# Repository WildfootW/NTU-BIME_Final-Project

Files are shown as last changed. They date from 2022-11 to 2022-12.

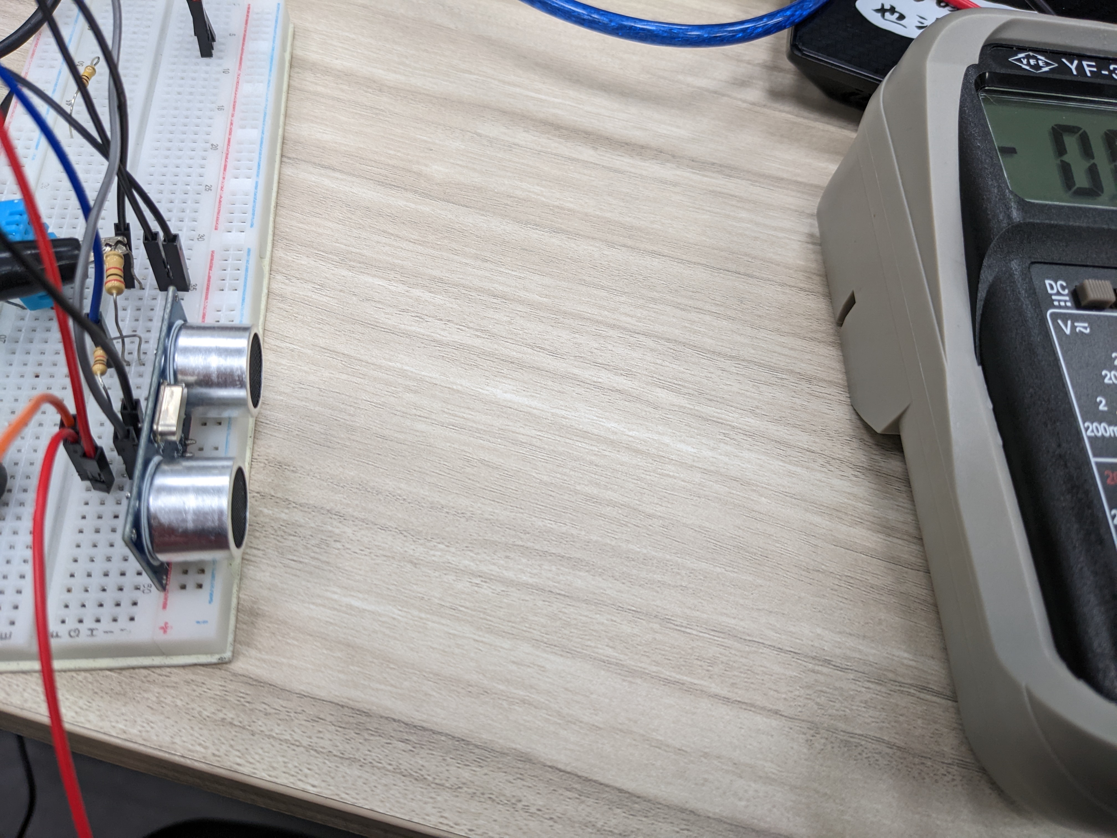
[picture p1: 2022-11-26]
Software/Components/HC-SR04/HC-SR04-2.3.jpg

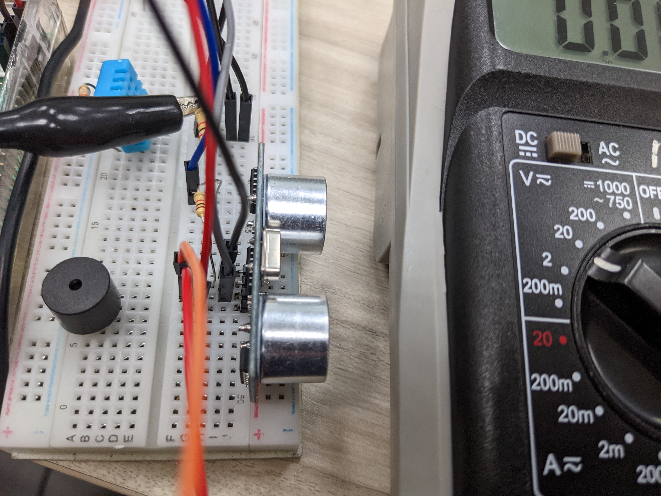
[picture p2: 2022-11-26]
Software/Components/HC-SR04/HC-SR04-1.3.jpg

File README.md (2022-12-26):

# BIME Final Project
###### tags: `README`
NTU BIME - Mechatronics 4 - Final Project

## Contributor
* Andrew 沈郁哲 (b07611012)
* Nick 張熯尹 (b08611038)
* Eric 張焜程 (b08611037)

### Work Distribution
* Program Manager: Andrew
* Platform Technical Manager: Andrew
* Mechanical - Main Structure: Eric
* Mechanical - Components: Eric
* Mechanical - Manufacturing: Eric
* Mechanical - Assembling: Eric, Nick
* Cable Management: Eric, Nick
* Industrial Design: Eric
* Thermal: Andrew
* Electrical - Schematic: Andrew
* Electrical - Layout: Andrew
* Electrical - Soldering: Andrew
* Software - Components: Nick
* Software - ROS: Nick, Andrew
* Software - OpenCV: Nick
* Supply Chain: Eric, Andrew
* Validation: Nick
* Driver: Nick
* Contact: Nick, Eric

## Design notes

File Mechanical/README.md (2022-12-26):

# BIME Final Project - Mechanical
[TOC]
###### tags: `Mechatronics`





## Main Deck
車子的主甲板，初版為直接將零件放在壓克力板上並手繪，再將其用電腦繪圖畫出，爾後買了紅色的大片壓克力板，用雷切機切出，其上乘載了大部分的零件，包括一片 RPi 、一片接在 RPi 上的電路板、兩個 H-bridge、兩個 HC-SR04 及一個伺服馬達。


## HC-SR04 Holder
3D 列印，作為 Sonar Sensor 的底座。


## Servo Motor Holder
3D 列印，將伺服馬達固定在主甲板上。


## Ring Ball Holder
作為我們設計的"夾爪"，一開始我的設計思路就是越簡單越好，最好是寫程式的人只需要做簡單的上下控制，於是想出了現在的這個環狀捕球器，畫圖時，先得知塑膠球的大小後，大概預測出捕球器所需的直徑，再將寬度和連接桿的長度依據車子設計的形狀做出決定，採用壓克力板雷切，尤其是我選用了比較厚的壓克力板，希望能更好的將球保持在環裡，最後用三秒膠固定在伺服馬達上。


## Motor Deck
放置四顆 TT 馬達的底板，並將很重的行動電源放置在馬達板的中間，使用壓克力板雷切製成。馬達板位於車體的最下層，以期將車子的重心盡量往下。


## TT Motor Holder
3D 列印，TT 馬達的固定座。

## Mecanum Wheel
當時我們決定使用四顆輪子，希望有更順暢的跑動，於是選用了麥克納姆輪，利用它能夠輕鬆執行前進、後退、旋轉、橫移的特點，升級我們電動車的跑動表現。
* Failed. Need two different direction x2. But we got same direction x4.

## Battery Deck
放置電池盒及 webcam holder 的板子，將電池板置於最上層，可以讓我們更好的更換電池，並且可以支撐我們的 webcam 收集影像所需的高度，讓我們的 webcam holder 不需很長很重，於壓克力板雷切製成。


## Webcam Holder
放置webcam的平台，提供webcam所需視野高度，3d列印製成。
* 
* SOLID, light-cured 3D printing
* 

## Car Garage
車子的美觀作品，作為電動車的車庫，讓車子由此衝出，由美術材料和冰棒棍製成。


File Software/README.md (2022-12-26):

# BIME Final Project - Software
[TOC]
###### tags: `Mechatronics`

# ROS

## Install
### Ubuntu
* [**ubuntu 20.04 ROS Noetic**](https://wiki.ros.org/ROS/Installation/TwoLineInstall/)
* [**Install ROS on Ubuntu**](https://wiki.ros.org/noetic/Installation/Ubuntu)
    * `wget -c https://raw.githubusercontent.com/qboticslabs/ros_install_noetic/master/ros_install_noetic.sh && chmod +x ./ros_install_noetic.sh && ./ros_install_noetic.sh`
### RPi & ROS from Source
* [**How to Install ROS Noetic on Raspberry Pi 4**](https://varhowto.com/install-ros-noetic-raspberry-pi-4/)
```
sudo sh -c 'echo "deb http://packages.ros.org/ros/ubuntu buster main" > /etc/apt/sources.list.d/ros-noetic.list'
sudo apt-key adv --keyserver 'hkp://keyserver.ubuntu.com:80' --recv-key C1CF6E31E6BADE8868B172B4F42ED6FBAB17C654
sudo apt update

sudo apt-get install -y python-rosdep python-rosinstall-generator python-wstool python-rosinstall build-essential cmake
sudo rosdep init
cat /etc/ros/rosdep/sources.list.d/20-default.list
rosdep update

mkdir ~/ros_catkin_ws
cd ~/ros_catkin_ws
rosinstall_generator ros_comm --rosdistro noetic --deps --wet-only --tar > noetic-ros_comm-wet.rosinstall
wstool init src noetic-ros_comm-wet.rosinstall
rosdep install -y --from-paths src --ignore-src --rosdistro noetic -r --os=debian:buster

sudo dphys-swapfile swapoff
sudo vim /etc/dphys-swapfile // CONF_SWAPSIZE=1024
sudo dphys-swapfile setup
sudo dphys-swapfile swapon
free -m

sudo src/catkin/bin/catkin_make_isolated --install -DCMAKE_BUILD_TYPE=Release --install-space /opt/ros/noetic -j1 -DPYTHON_EXECUTABLE=/usr/bin/python3
source /opt/ros/noetic/setup.bash
```
* [**Installing ROS Kinetic on the Raspberry Pi**](https://wiki.ros.org/ROSberryPi/Installing%20ROS%20Kinetic%20on%20the%20Raspberry%20Pi) - This is the official version for Kinetic. Has "Maintaining a Source Checkout"
```
cd ~/ros_catkin_ws
rosinstall_generator ros_comm ros_control joystick_drivers --rosdistro noetic --deps --wet-only --tar > noetic-custom_ros.rosinstall
rosinstall_generator ros_comm turtlesim usb_cam --rosdistro noetic --deps --wet-only --tar > noetic-custom_ros.rosinstall

wstool merge -t src noetic-custom_ros.rosinstall
wstool update -t src

rosdep install -y --from-paths src --ignore-src --rosdistro noetic -r --os=debian:buster
sudo src/catkin/bin/catkin_make_isolated --install -DCMAKE_BUILD_TYPE=Release --install-space /opt/ros/noetic -j1 -DPYTHON_EXECUTABLE=/usr/bin/python3
```
### Packages
* `sudo apt-get install ros-$(rosversion -d)-`
* `sudo apt-get install ros-$(rosversion -d)-turtlesim`

### Issues
#### INSTALL ROSDEP
* 建立 package 遇到問題
* 

#### Build only the pkg

https://answers.ros.org/question/54178/how-to-build-just-one-package-using-catkin_make/
`sudo src/catkin/bin/catkin_make_isolated --only-pkg-with-deps bime_final --merge -j2 -DPYTHON_EXECUTABLE=/usr/bin/python3`

#### Can't Execute ROSRUN after source devel/setup.bash
[Ros commands no longer working after source catkin_ws/devel/setup.bash](https://answers.ros.org/question/349276/ros-commands-no-longer-working-after-source-catkin_wsdevelsetupbash/)
* `source /opt/ros/melodic/setup.bash` and then `source devel/setup.bash --extend`

* `sudo src/catkin/bin/catkin_make_isolated --install -DCMAKE_BUILD_TYPE=Release --install-space /opt/ros/noetic -j2 -DPYTHON_EXECUTABLE=/usr/bin/python3`
    * would repair, but very slow on RPi (Seems recompile whole ROS system)

#### catkin_make vs catkin_make_isolated
* [catkin_make vs catkin_make_isolated, which is preferred?](https://answers.ros.org/question/320613/catkin_make-vs-catkin_make_isolated-which-is-preferred/)


## Connect Master
* [**Connecting Raspberry Pi with PC over LAN**](https://razbotics.wordpress.com/2018/01/23/ros-distributed-systems/)

## Components
### DHT11
[DHT11 introudction](https://blog.csdn.net/wgj99991111/article/details/53749144)


### OpenCV / Camera
* [Ball Track](https://github.com/tizianofiorenzani/ros_tutorials/tree/master/opencv)
* [CV Camera Tourial](https://www.theconstructsim.com/how-to-install-a-usb-camera-in-turtlebot3/)
* [opencv turtlebot2-tutorials](https://dabit-industries.github.io/turtlebot2-tutorials/14b-OpenCV2_Python.html)
[ROS Developers LIVE Class #86: How to use OpenCV with ROS](https://www.youtube.com/watch?v=0C0gOsLoP9k)
* [cv camera](https://www.theconstructsim.com/how-to-install-a-usb-camera-in-turtlebot3/)
* [cv tracking object](https://github.com/behnamasadi/OpenCVProjects)
* [ROS Tutorial 001: Remotely connecting to webcam using Raspberry Pi 3 and ROS](https://github.com/yev-d/tutos/blob/master/ROS/Tutorial-001/Remotely-connecting-to-webcam-using-Raspberry-Pi-3-and-ROS.md)
* [How to use USB camera with ROS on Raspberry Pi - image_view and web streaming](https://roboticsweekends.blogspot.com/2017/12/how-to-use-usb-camera-with-ros-on.html)
* [rosmaster connect](https://hollyqood.wordpress.com/2017/05/17/ros%E4%B8%8A%E5%90%8C%E6%99%82%E4%BD%BF%E7%94%A8%E5%A4%9A%E5%80%8B%E7%92%B0%E5%A2%83%E9%80%A3%E6%8E%A5masterroscore/) error: cannot connect 
* [**How to use a USB camera with ROS on the Raspberry Pi or BeagleBone Blue - for streaming video to a large computer**](https://sudonull.com/post/14791-How-to-use-a-USB-camera-with-ROS-on-the-Raspberry-Pi-or-BeagleBone-Blue-for-streaming-video-to-a-lar)
* [usb_cam Package Summary](http://wiki.ros.org/usb_cam#usb_cam_node)
* [camera_calibration set_camera_info Service not found](https://answers.ros.org/question/200154/camera_calibration-set_camera_info-service-not-found/)
#### Issues
* [image_view-2] process has died [pid 2280, exit code -11, cmd /opt/ros/noetic/lib/image_view/image_view image:=/usb_cam/image_raw __name:=image_view __log:=/home/ubuntu/.ros/log/ac8e131c-5993-11ed-ba8b-c538adf0cb0e/image_view-2.log].
log file: /home/ubuntu/.ros/log/ac8e131c-5993-11ed-ba8b-c538adf0cb0e/image_view-2*.log
    * [usb cam error](https://www.twblogs.net/a/5c0a98e1bd9eee6fb37bccd7)
* [usb cam service](https://answers.ros.org/question/200154/camera_calibration-set_camera_info-service-not-found/)

##### USB_CAM Launch

* Can be ignore on RPi. only need image-view on VM

##### Webcam Issue
* [**Ubuntu Community Webcam**](https://help.ubuntu.com/community/Webcam)
```
sudo usermod -a -G video $LOGNAME 
sudo apt install v4l-utils
sudo apt install ffmpeg
ffplay -f video4linux2 -input_format mjpeg -framerate 5 -video_size 640*480 /dev/video0
```


```
Driver Info:                    
        Driver name      : uvcvideo                                     
        Card type        : UVC Camera (046d:081b)
        Bus info         : usb-0000:02:03.0-1           
        Driver version   : 5.15.64
        Capabilities     : 0x84a00001
                Video Capture                                           
                Metadata Capture                                        
                Streaming
                Extended Pix Format                                                                                                              
                Device Capabilities                                                                                                              
        Device Caps      : 0x04200001
                Video Capture                                           
                Streaming                                               
                Extended Pix Format
Media Driver Info:                                                                                                                               
        Driver name      : uvcvideo                                                                                                              
        Model            : UVC Camera (046d:081b)                                                                                                
        Serial           : 9D37D020                                     
        Bus info         : usb-0000:02:03.0-1                                                                                                    
        Media version    : 5.15.64                                                                                                               
        Hardware revision: 0x00000012 (18) 
        Driver version   : 5.15.64                                      
Interface Info:                                                         
        ID               : 0x03000002                                                                                                            
        Type             : V4L Video                                                                                                             
Entity Info:                                                                                                                                     
        ID               : 0x00000001 (1)                                                                                                        
        Name             : UVC Camera (046d:081b)
        Function         : V4L2 I/O                                     
        Flags         : default                                                                                                                  
        Pad 0x01000007   : 0: Sink                                      
          Link 0x02000019: from remote pad 0x100000a of entity 'Extension 4': Data, Enabled, Immutable
Priority: 2
Video input : 0 (Camera 1: ok)
Format Video Capture:
        Width/Height      : 640/480
        Pixel Format      : 'MJPG' (Motion-JPEG)
        Field             : None
        Bytes per Line    : 0
        Size Image        : 614400
        Colorspace        : sRGB
        Transfer Function : Rec. 709
        YCbCr/HSV Encoding: ITU-R 601
        Quantization      : Default (maps to Full Range)
        Flags             : 
Crop Capability Video Capture:
        Bounds      : Left 0, Top 0, Width 640, Height 480
        Default     : Left 0, Top 0, Width 640, Height 480
        Pixel Aspect: 1/1
Selection Video Capture: crop_default, Left 0, Top 0, Width 640, Height 480, Flags: 
Selection Video Capture: crop_bounds, Left 0, Top 0, Width 640, Height 480, Flags: 
Streaming Parameters Video Capture:
        Capabilities     : timeperframe
        Frames per second: 5.000 (5/1)
        Read buffers     : 0
                     brightness 0x00980900 (int)    : min=0 max=255 step=1 default=128 value=128
                       contrast 0x00980901 (int)    : min=0 max=255 step=1 default=32 value=32
                     saturation 0x00980902 (int)    : min=0 max=255 step=1 default=32 value=32
 white_balance_temperature_auto 0x0098090c (bool)   : default=1 value=1
                           gain 0x00980913 (int)    : min=0 max=255 step=1 default=64 value=1
           power_line_frequency 0x00980918 (menu)   : min=0 max=2 default=2 value=2
                                0: Disabled
                                1: 50 Hz
                                2: 60 Hz
      white_balance_temperature 0x0098091a (int)    : min=0 max=10000 step=10 default=4000 value=1070 flags=inactive
                      sharpness 0x0098091b (int)    : min=0 max=255 step=1 default=24 value=24
         backlight_compensation 0x0098091c (int)    : min=0 max=1 step=1 default=0 value=0
                  exposure_auto 0x009a0901 (menu)   : min=0 max=3 default=3 value=3
                                1: Manual Mode
                                3: Aperture Priority Mode
              exposure_absolute 0x009a0902 (int)    : min=1 max=10000 step=1 default=166 value=656 flags=inactive
         exposure_auto_priority 0x009a0903 (bool)   : default=0 value=1
```
* fixed: need to set the USB port to 3.1



# UbiquityRobotics (Discard)
* https://learn.ubiquityrobotics.com/noetic_pi_image_downloads
* Strange behavior - discard
## rpi wifi connect
[wifi connect](https://learn.ubiquityrobotics.com/noetic_quick_start_microsd)
[wifi connect](https://learn.ubiquityrobotics.com/noetic_quick_start_connecting)
```
pifi list seen
sudo pifi add EELAB-Teach-5G bime0307
sudo pifi add Xiaomi5G 83662290
sudo pifi add Xiaomi5G ntubime405
sudo pifi add BBLAB_New ntubime405 
sudo reboot
```

## Issues
*

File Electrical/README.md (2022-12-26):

# BIME Final Project - Electrical
[TOC]
###### tags: `Mechatronics`

# BIME Final ~~HAT~~ PCB
* Reference Diameter
    * 

 
 

* [How to Export Gerber](https://www.elecrow.com/wiki/index.php?title=How_to_export_gerber_files_from_Altium_designer)

## Todo
* add Pinout
* Add 6V Switch
* Correct Fan Position
* repoly first layer
* reverse 10x2 pin
* Correct Resistor Ohm (R6789)

https://roboticsbackend.com/raspberry-pi-3-pins/#Reserved_pins
[**raspberrypi / hats**](https://github.com/raspberrypi/hats)
* move buzzer to pin7
* move Fan_Tach to pin26

## 3V3 to 5V
### Unidirectional
* [Amplify PWM Signal from exactly 0-3.3V to 0-5V](https://electronics.stackexchange.com/questions/359994/amplify-pwm-signal-from-exactly-0-3-3v-to-0-5v)
* Gate
    * 
* BJT
    * 
* [Auto fan control trouble shooting](https://forums.raspberrypi.com/viewtopic.php?t=328330)
    * 


### Bidirectional OC/OD open-collector or open-drain
* Buffer
    * [ I2C buffers overview ](https://youtu.be/WZWSB2-kvuA)
    * 
* Translator
    * [ I2C translators overview ](https://youtu.be/_Rxt1LLvtf4)
    * 
    
* Compiled Tips ‘N Tricks Guide


# Buck Converter
* [EasyEDA Project](https://u.easyeda.com/account/user/projects/index/detail?project=bbbc860793c24aa5b11dd05bab18da10&folder=all)

## Manufacture
* JLCPCBA
* [【教學】最簡單的PCB電路板教學，從設計到廠商製造一次搞定。JLCPCB](https://youtu.be/yPJ-4nEXykE)
* [製作自己的第一片PCB—使用JLCPCB、EasyEDA](https://bo-sgoldhouse.blogspot.com/2021/08/pcb-jlcpcb-easyeda.html)
* 
* 

## RPi 3B+ Power
* [Cable](https://shopee.tw/-%E7%89%A9%E8%81%AF%E6%B1%AA%E6%B1%AA-%E5%AF%A6%E7%94%A8-Micro-USB-%E9%96%8B%E9%97%9C%E5%85%85%E9%9B%BB%E7%B7%9A%E9%9B%BB%E6%BA%90%E7%B7%9A%E9%81%A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)
* [What is the expected behaviour of the PWR LED on Pi3B+](https://forums.raspberrypi.com/viewtopic.php?t=212350)
* [RPi 3 B: Strange behaviour of power LED](https://forums.raspberrypi.com/viewtopic.php?t=147447)
* [What do system LEDs signify?](https://raspberrypi.stackexchange.com/questions/871/what-do-system-leds-signify/60563#60563)
* [Raspberry Pi 3 Model B+ Stable Red Light When Powered Up](https://raspberrypi.stackexchange.com/questions/83090/raspberry-pi-3-model-b-stable-red-light-when-powered-up)
* 
* 

## Circuit



### MP2315
[How to Design 12V to 5V Buck Converter 一起设计一款好用的12V转5V电源模块](https://www.youtube.com/playlist?list=PLBpCr1fi_kFbyh0TMSjQk9jeb3ThH9svX)

#### Schematic




#### Layout
* Ver.傳奇帝 
	* https://oshwhub.com/jie.li/dcdc_mp2315
	* 
	* 
	* 

* Ver.孫
	* https://oshwhub.com/sunhaoqin/dcdc_mp2315
	* 
	* 
    
#### Test
* No Loading
    * 
* RPi Power on
    * 
* RPi not stable while operation
    * 
    * The PWR LED will turn off if the current of 12V over 0.3A. The RPi did not reset. The oscilloscope can neither find the 5V drop.
    * Replace the module by LM-2596. The PWR LED become more stable with less LED off. The current is less.
    * Connect the USB A direct to 5V Power supply. The PWR LED is stable as LM-2596. (not for sure). And current below 0.2A.
    * Connect with my power bank. RPi is not stable as well.
    * Connect direct to AC Converter. The PWR LED is very stable.

### LM-2596

* [ LM2596S 降壓電源 DC-DC 降壓型 電源模組  具備電源指示燈 ](https://www.taiwaniot.com.tw/product/lm2596s-%E9%99%8D%E5%A3%93%E9%9B%BB%E6%BA%90-dc-dc-%E9%99%8D%E5%A3%93%E5%9E%8B-%E9%9B%BB%E6%BA%90%E6%A8%A1%E7%B5%84-%E5%8F%AF%E8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)

#### Module
* Fake LM2596 & Detail Test
* [ Counterfeit LM2596 Regulator Boards ](https://k6jca.blogspot.com/2018/02/counterfeit-lm2596-regulator-boards.html)
*

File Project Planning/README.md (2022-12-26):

# BIME Final Project - Components
[TOC]
###### tags: `Mechatronics`

# Software & Circuit
## Reference
* [Duckiebot](https://docs.duckietown.org/daffy/opmanual_duckiebot/out/duckiebot_configurations.html)
* [ nasa-jpl / open-source-rover ](https://github.com/nasa-jpl/open-source-rover)
* ROS Ecosystem
* [t1m0thyj / picar](https://github.com/t1m0thyj/picar)
    * [ How to Make Raspberry Pi Car at home ](https://youtu.be/FyMq5KOcgTg)

## Communication
### Video Transmitter
[ 5.8GHz Vs. 1300MHz FPV Penetrating Power Test - RCTESTFLIGHT - ](https://youtu.be/LltDtKs2sQ4)

### FPV Transmitter / Receiver
* [Drones and Model Aircraft - Frequency](https://drones.stackexchange.com/questions/810/why-is-5-8ghz-used-for-fpv-and-2-4ghz-use-for-transmitters)


### On Screen Display (OSD)
* [Raspberry Pi Zero FPV camera and OSD](https://hackaday.io/project/12450-raspberry-pi-zero-fpv-camera-and-osd)

### Direction

## Power
* Battery
* BMS

RPi input from USB Header 5V

http://www.pidramble.com/wiki/benchmarks/power-consumption

## Sensor
### Camera
* C310 HD
* Intel® RealSense™ depth camera D435

### Obstacle
* Depth Camera
* Sonic
* IR

### Thermal
https://lastminuteengineers.com/mlx90614-ir-temperature-sensor-arduino-tutorial/

測量熱源的關卡設定是在熱源前面35-45公分處（助教指定距離），定位後車輛停止五秒感測溫度，目前實際測試看來，溫度在攝氏40-45度之間。



* Fan

### Accelerometer?
MPU-6050


https://shop.cpu.com.tw/product/45284/info/

## Actuator
### PWM
* [Adafruit 16-Channel 12-bit PWM/Servo Driver - I2C interface - PCA9685](https://www.adafruit.com/product/815)
* [What's the difference between soft PWM and PWM](https://raspberrypi.stackexchange.com/questions/100641/whats-the-difference-between-soft-pwm-and-pwm)
* [ besp9510 /dma_pwm ](https://github.com/besp9510/dma_pwm)
### H-Bridge


### Wheel Motor
* [Adafruit TT](https://www.adafruit.com/product/3777)
* 
* 

### Gripper
* [Tower Pro SG90](https://www.towerpro.com.tw/product/sg90-7/)
* 

### Buzzer

# Mechanical
## References
* [A gamified simulator and physical platform for self-driving algorithm training and validation](https://www.researchgate.net/figure/This-1-10th-scale-buggy-features-a-Raspberry-Pi-3B-Navio2-interface-board-Logitech_fig10_337336443)
    * 
* [ nasa-jpl /open-source-rover ](https://github.com/nasa-jpl/open-source-rover)

## Car Body
* 4x Mecanum wheel W/O Suspenstion
* 4x Mecanum wheel W/ Suspenstion
    * https://youtu.be/K1yDDmkbaq4
* 3x Omni Wheel
* 4x Normal Wheel W/ Suspension
    * HSP94186 (https://youtu.be/iLiI_IRedhI)
    * [Donkey® Car](https://docs.donkeycar.com)
* 4x Normal Wheel W/O Suspension
* 2x Normal Wheel W/ Ball Roller
    * [Li-Wei Yang - Mechatronics 4](https://youtu.be/lFlVofkHzSU)

## Gripper
* 球的直徑大約為6.6-6.7公分

## Holders
* Camera
* Thermal
* ...

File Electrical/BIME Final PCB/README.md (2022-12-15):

* [Buck Converter MP2315](https://oshwlab.com/wildfootw/buck-converter-mp2315)

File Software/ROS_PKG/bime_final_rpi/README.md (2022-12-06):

# ROS PKG - bime_final_rpi
## Cheatsheet
* Compile this package on RPi
```
sudo src/catkin/bin/catkin_make_isolated --only-pkg-with-deps bime_final_rpi --merge -j4 -DPYTHON_EXECUTABLE=/usr/bin/python3
```

## Basic Information
### Dependence
* [USB_CAM](https://index.ros.org/p/usb_cam/github-ros-drivers-usb_cam/)

## Component
### Mecanum wheel
Move Direction

## Reference
[Raspberry Pi - PWM](https://sourceforge.net/p/raspberry-gpio-python/wiki/PWM/)

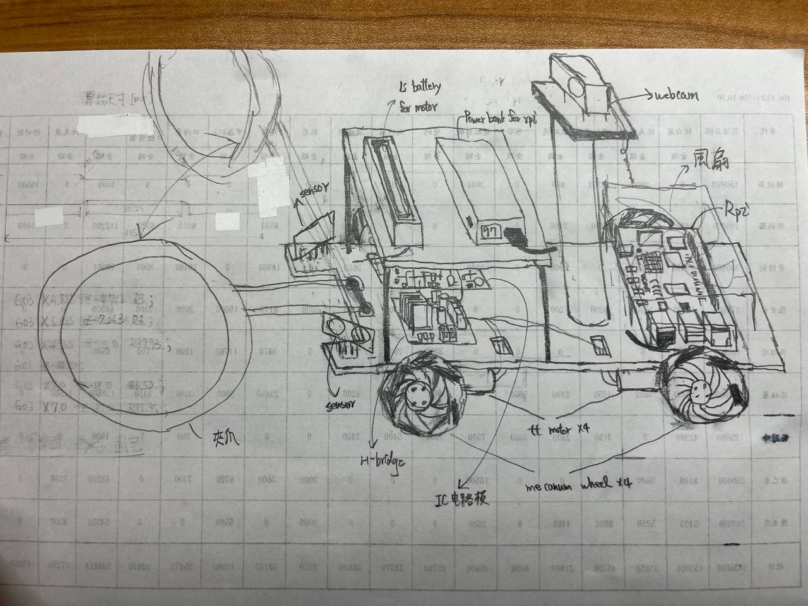
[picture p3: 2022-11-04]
Mechanical/Mechanical Prototype v1.0.jpg

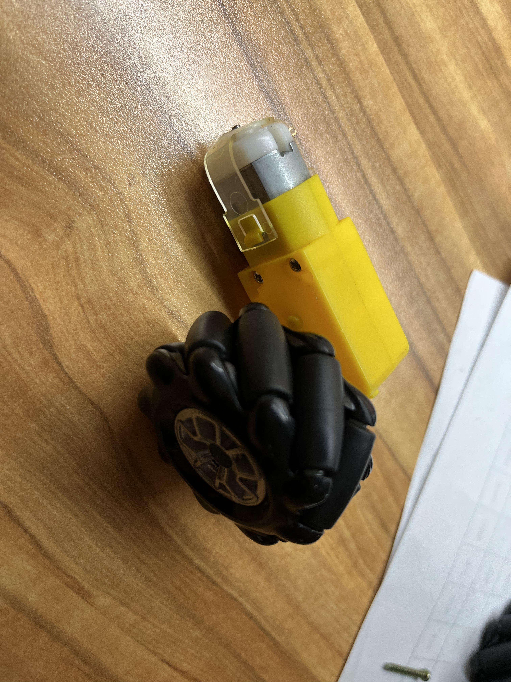
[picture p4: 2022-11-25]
Mechanical/Mecanum Wheel.jpg

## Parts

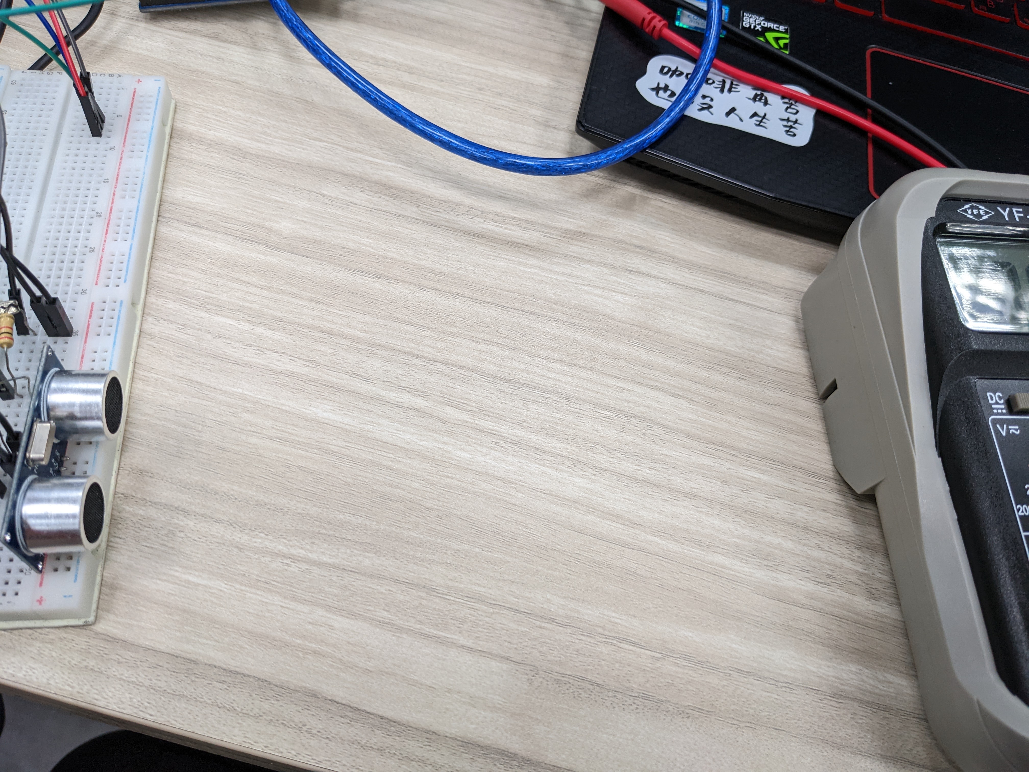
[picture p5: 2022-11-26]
Software/Components/HC-SR04/HC-SR04-3.3.jpg

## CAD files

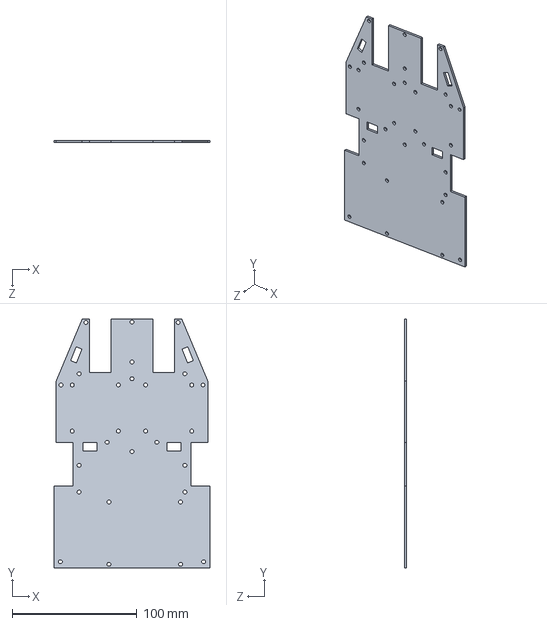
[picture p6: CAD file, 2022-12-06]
Mechanical/Main Deck.SLDPRT
125.0 x 200.0 x 2.00 mm

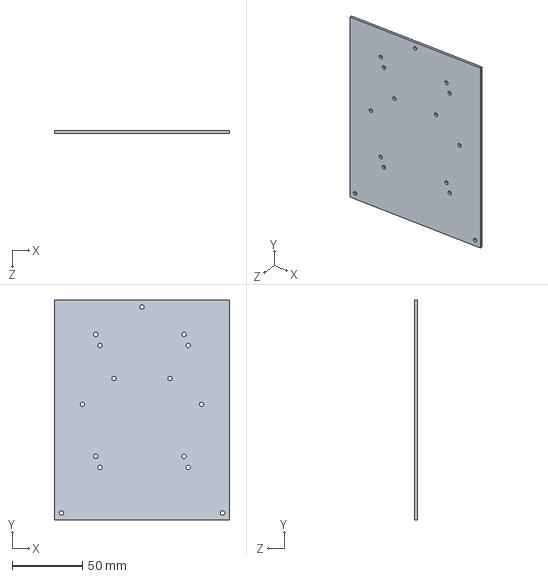
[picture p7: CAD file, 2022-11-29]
Mechanical/Motor Deck.SLDPRT
125.0 x 157.0 x 2.00 mm

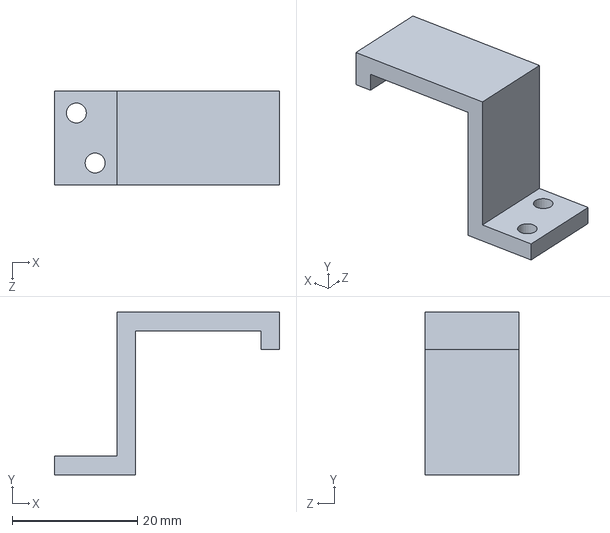
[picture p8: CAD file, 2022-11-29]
Mechanical/TT Motor Holder.SLDPRT
36.0 x 26.0 x 15.0 mm

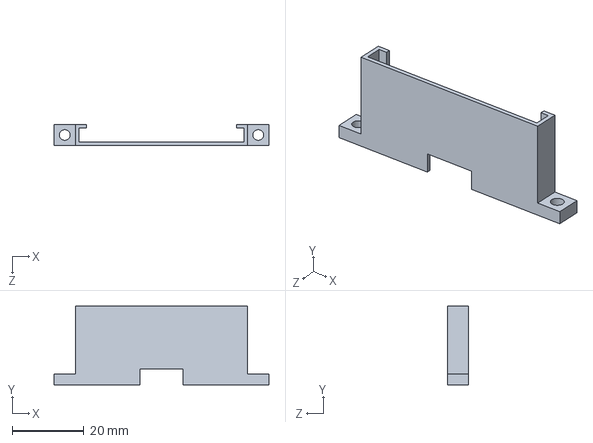
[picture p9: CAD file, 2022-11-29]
Mechanical/HC-SR04 Holder.SLDPRT
60.0 x 22.0 x 6.00 mm

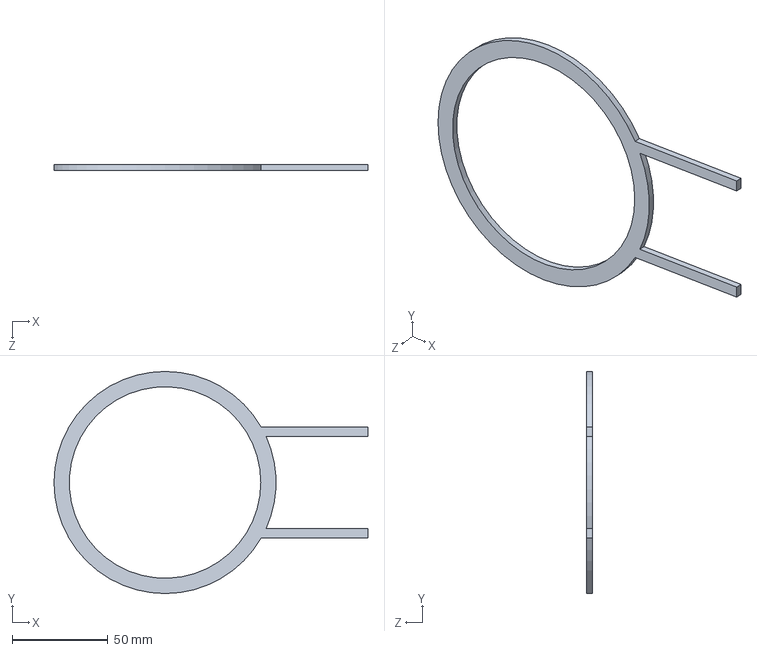
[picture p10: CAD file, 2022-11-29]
Mechanical/Ring Ball Holder.SLDPRT
164.0 x 116.0 x 3.00 mm

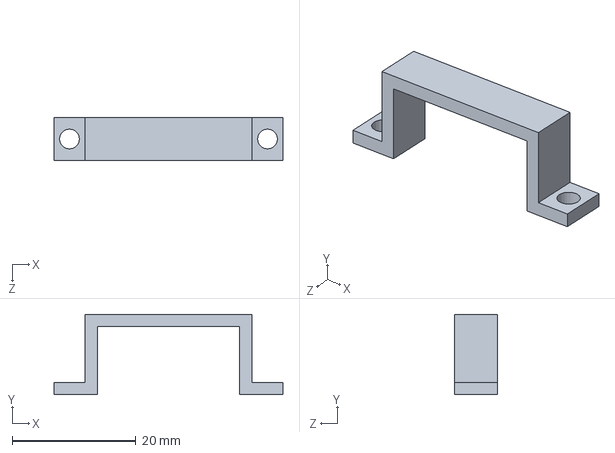
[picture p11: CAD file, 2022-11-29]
Mechanical/Servo Motor Holder.SLDPRT
37.0 x 13.0 x 7.00 mm

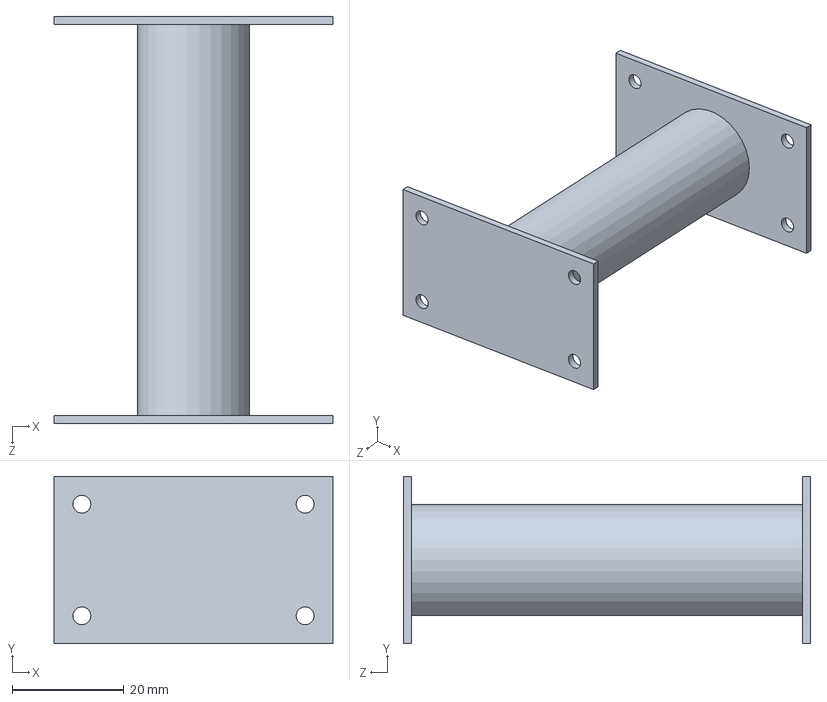
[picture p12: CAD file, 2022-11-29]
Mechanical/Webcam Holder.SLDPRT
50.0 x 30.0 x 73.0 mm

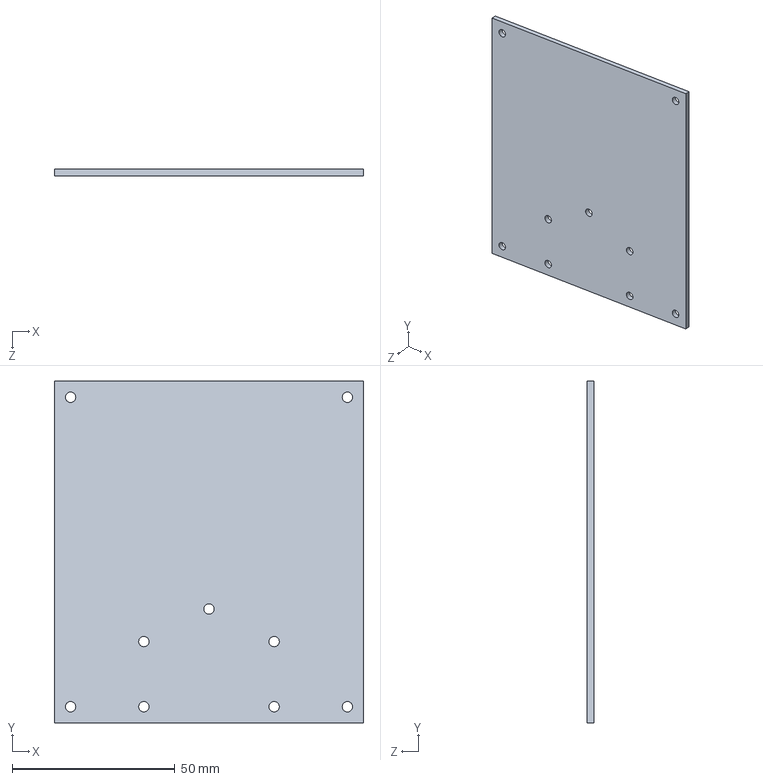
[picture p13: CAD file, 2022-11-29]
Mechanical/Battery Deck.SLDPRT
95.0 x 105.0 x 2.00 mm

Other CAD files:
Electrical/BIME Final PCB/BoardShape.SLDPRT
Electrical/BIME Final PCB/BoardShape.DXF
Mechanical/Battery Deck.DXF
Mechanical/HC-SR04 Holder.STL
Mechanical/Main Deck.DXF
Mechanical/Motor Deck.DXF
Mechanical/Ring Ball Holder.DXF
Mechanical/Servo Motor Holder.STL
Mechanical/TT Motor Holder.STL
Mechanical/Webcam Holder.STL

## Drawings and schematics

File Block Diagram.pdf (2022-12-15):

VM

### Ubuntu 20.04

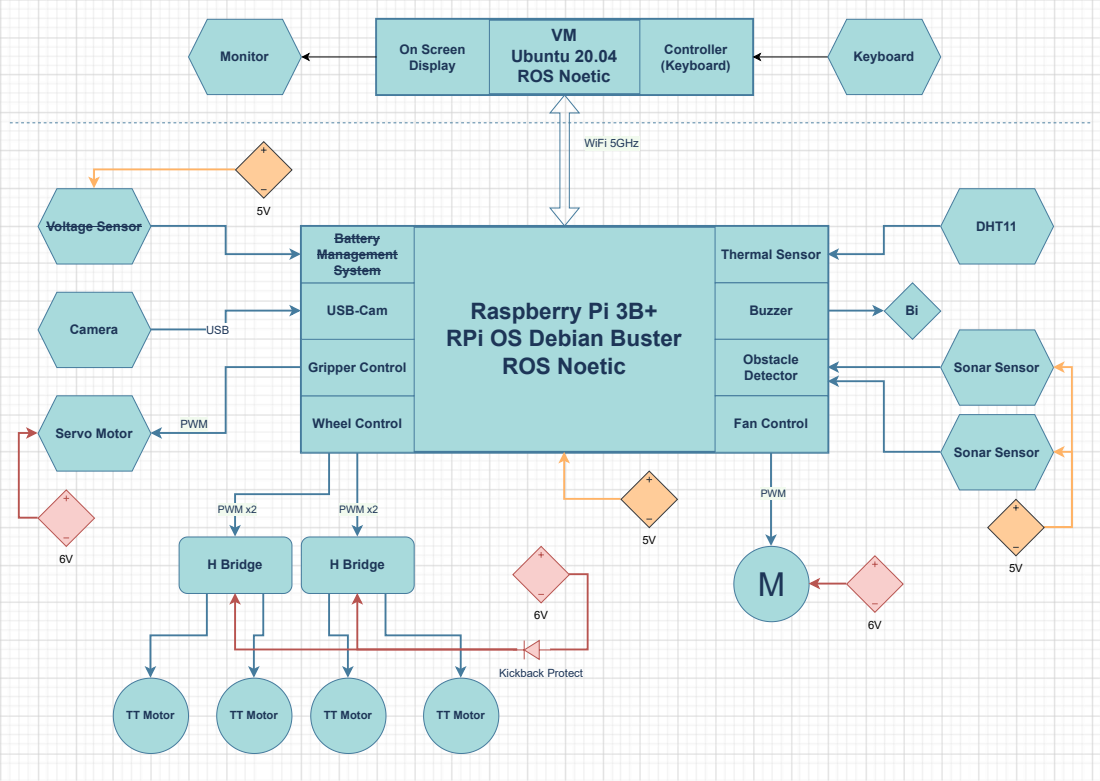
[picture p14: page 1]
ROS Noetic; WiFi 5GHz; PWM x2; PWM; Wheel Control; Gripper Control; USB-Cam; Battery Management System; Thermal Sensor; Buzzer; Obstacle Detector; Fan Control; Voltage Sensor; Camera; USB; Servo Motor; H Bridge; DHT11; Sonar Sensor; TT Motor; Kickback Protect; On Screen Display; Controller (Keyboard); Monitor; Keyboard

Raspberry Pi 3B+
RPi OS Debian Buster
ROS Noetic

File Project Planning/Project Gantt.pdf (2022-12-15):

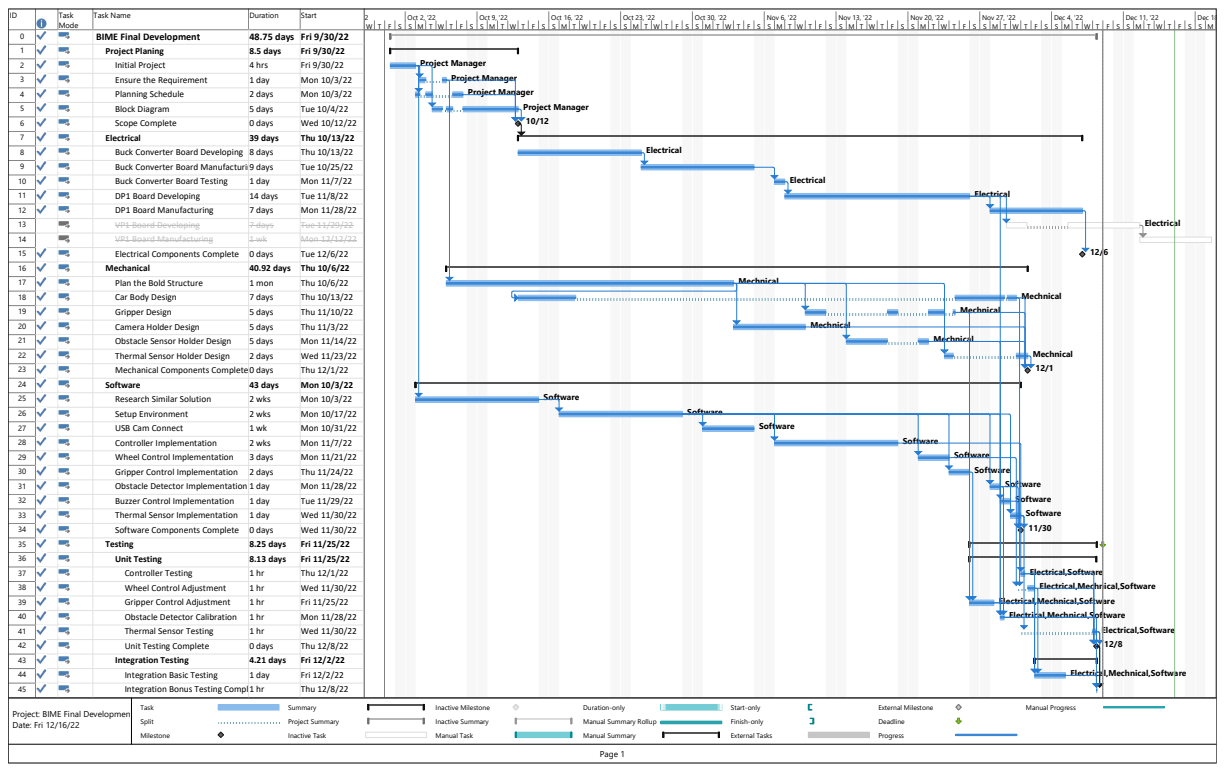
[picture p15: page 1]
Project Manager; Project Manager 10/12; Electrical; Mechnical; Mechnical 12/1; Software Software Software 11/30; Electrical,Software 12/8; Oct 2, '22; Oct 9, '22; Oct 16, '22; Oct 23, '22; Oct 30, '22; Nov 6, '22; Nov 13, '22; Nov 20, '22; Nov 27, '22; Dec 4, '22; Dec 11, '22; Dec 18, '22; Task; Split; Milestone; Summary; Project Summary; Inactive Task; Inactive Milestone; Inactive Summary; Manual Task; Start-only; Finish-only; External Tasks; External Milestone; Deadline; Progress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

ID | Task Mode | Task Name | Duration | Start
0 | | BIME Final Development | 48.75 days | Fri 9/30/22
1 | | Project Planing | 8.5 days | Fri 9/30/22
2 | | Initial Project | 4 hrs | Fri 9/30/22
3 | | Ensure the Requirement | 1 day | Mon 10/3/22
4 | | Planning Schedule | 2 days | Mon 10/3/22
5 | | Block Diagram | 5 days | Tue 10/4/22
6 | | Scope Complete | 0 days | Wed 10/12/22
7 | | Electrical | 39 days | Thu 10/13/22
8 | | Buck Converter Board Developing | 8 days | Thu 10/13/22
9 | | Buck Converter Board Manufacturing9 days | | Tue 10/25/22
10 | | Buck Converter Board Testing | 1 day | Mon 11/7/22
11 | | DP1 Board Developing | 14 days | Tue 11/8/22
12 | | DP1 Board Manufacturing | 7 days | Mon 11/28/22
13 | | VP1 Board Developing | 7 days | Tue 11/29/22
14 | | VP1 Board Manufacturing | 1 wk | Mon 12/12/22
15 | | Electrical Components Complete | 0 days | Tue 12/6/22
16 | | Mechanical | 40.92 days | Thu 10/6/22
17 | | Plan the Bold Structure | 1 mon | Thu 10/6/22
18 | | Car Body Design | 7 days | Thu 10/13/22
19 | | Gripper Design | 5 days | Thu 11/10/22
20 | | Camera Holder Design | 5 days | Thu 11/3/22
21 | | Obstacle Sensor Holder Design | 5 days | Mon 11/14/22
22 | | Thermal Sensor Holder Design | 2 days | Wed 11/23/22
23 | | Mechanical Components Complete0 days | | Thu 12/1/22
24 | | Software | 43 days | Mon 10/3/22
25 | | Research Similar Solution | 2 wks | Mon 10/3/22
26 | | Setup Environment | 2 wks | Mon 10/17/22
27 | | USB Cam Connect | 1 wk | Mon 10/31/22
28 | | Controller Implementation | 2 wks | Mon 11/7/22
29 | | Wheel Control Implementation | 3 days | Mon 11/21/22
30 | | Gripper Control Implementation | 2 days | Thu 11/24/22
31 | | Obstacle Detector Implementation 1 day | | Mon 11/28/22
32 | | Buzzer Control Implementation | 1 day | Tue 11/29/22
33 | | Thermal Sensor Implementation | 1 day | Wed 11/30/22
34 | | Software Components Complete | 0 days | Wed 11/30/22
35 | | Testing | 8.25 days | Fri 11/25/22
36 | | Unit Testing | 8.13 days | Fri 11/25/22
37 | | Controller Testing | 1 hr | Thu 12/1/22
38 | | Wheel Control Adjustment | 1 hr | Wed 11/30/22
39 | | Gripper Control Adjustment | 1 hr | Fri 11/25/22
40 | | Obstacle Detector Calibration | 1 hr | Mon 11/28/22
41 | | Thermal Sensor Testing | 1 hr | Wed 11/30/22
42 | | Unit Testing Complete | 0 days | Thu 12/8/22
43 | | Integration Testing | 4.21 days | Fri 12/2/22
44 | | Integration Basic Testing | 1 day | Fri 12/2/22
45 | | Integration Bonus Testing Complete 1 hr | | Thu 12/8/22

Project Manager

Mechnical

Software | | | Software

Software

Electrical,Software
Electrical,Mechnical,Software

Duration-only
Manual Summary Rollup
Manual Summary
Page 1

Project: BIME Final Developmen Date: Fri 12/16/22

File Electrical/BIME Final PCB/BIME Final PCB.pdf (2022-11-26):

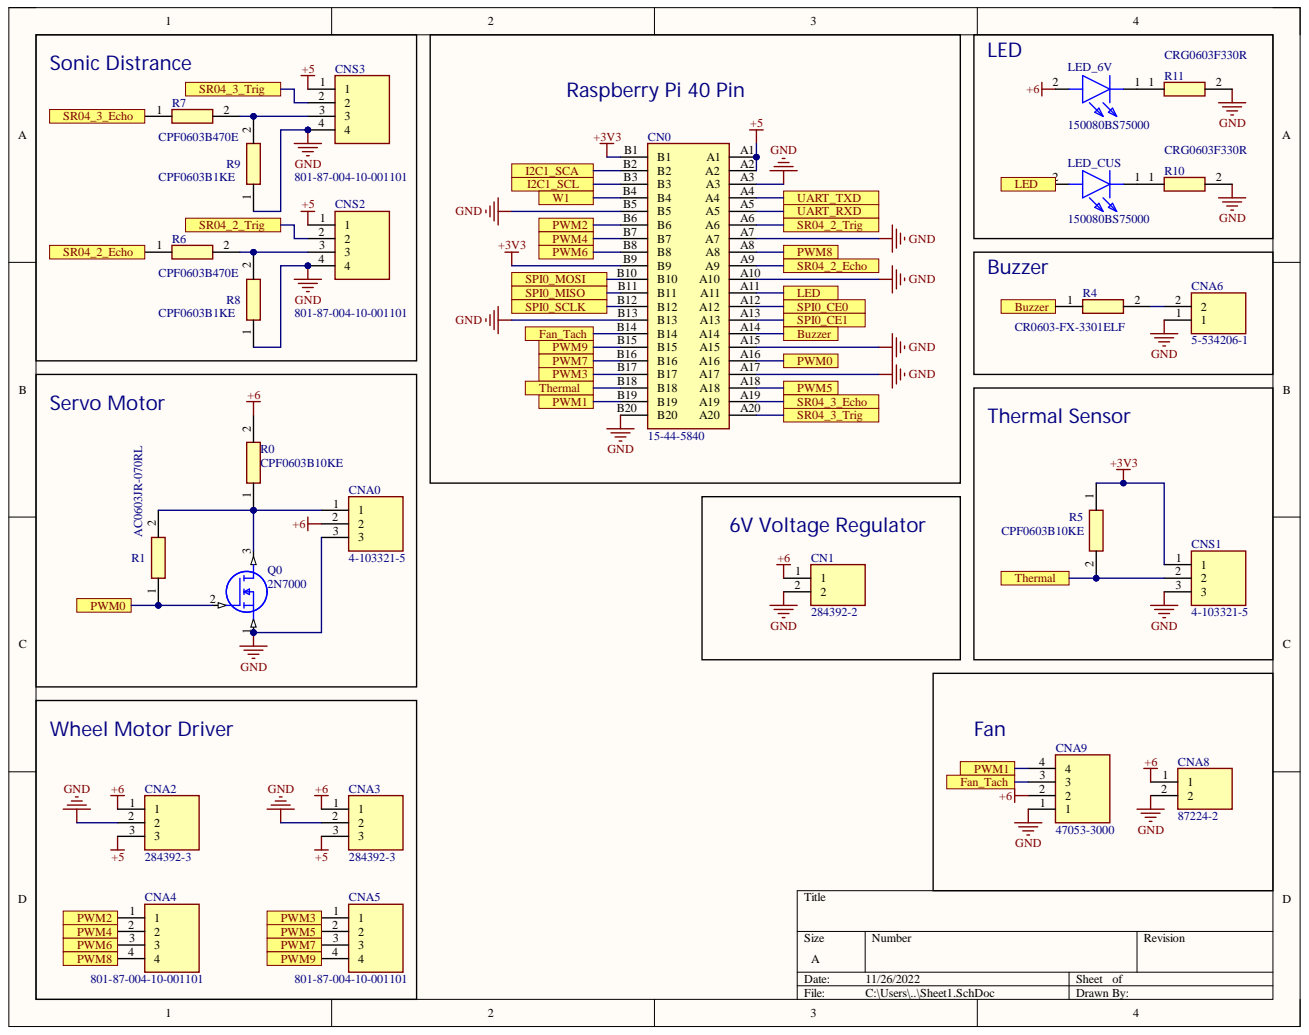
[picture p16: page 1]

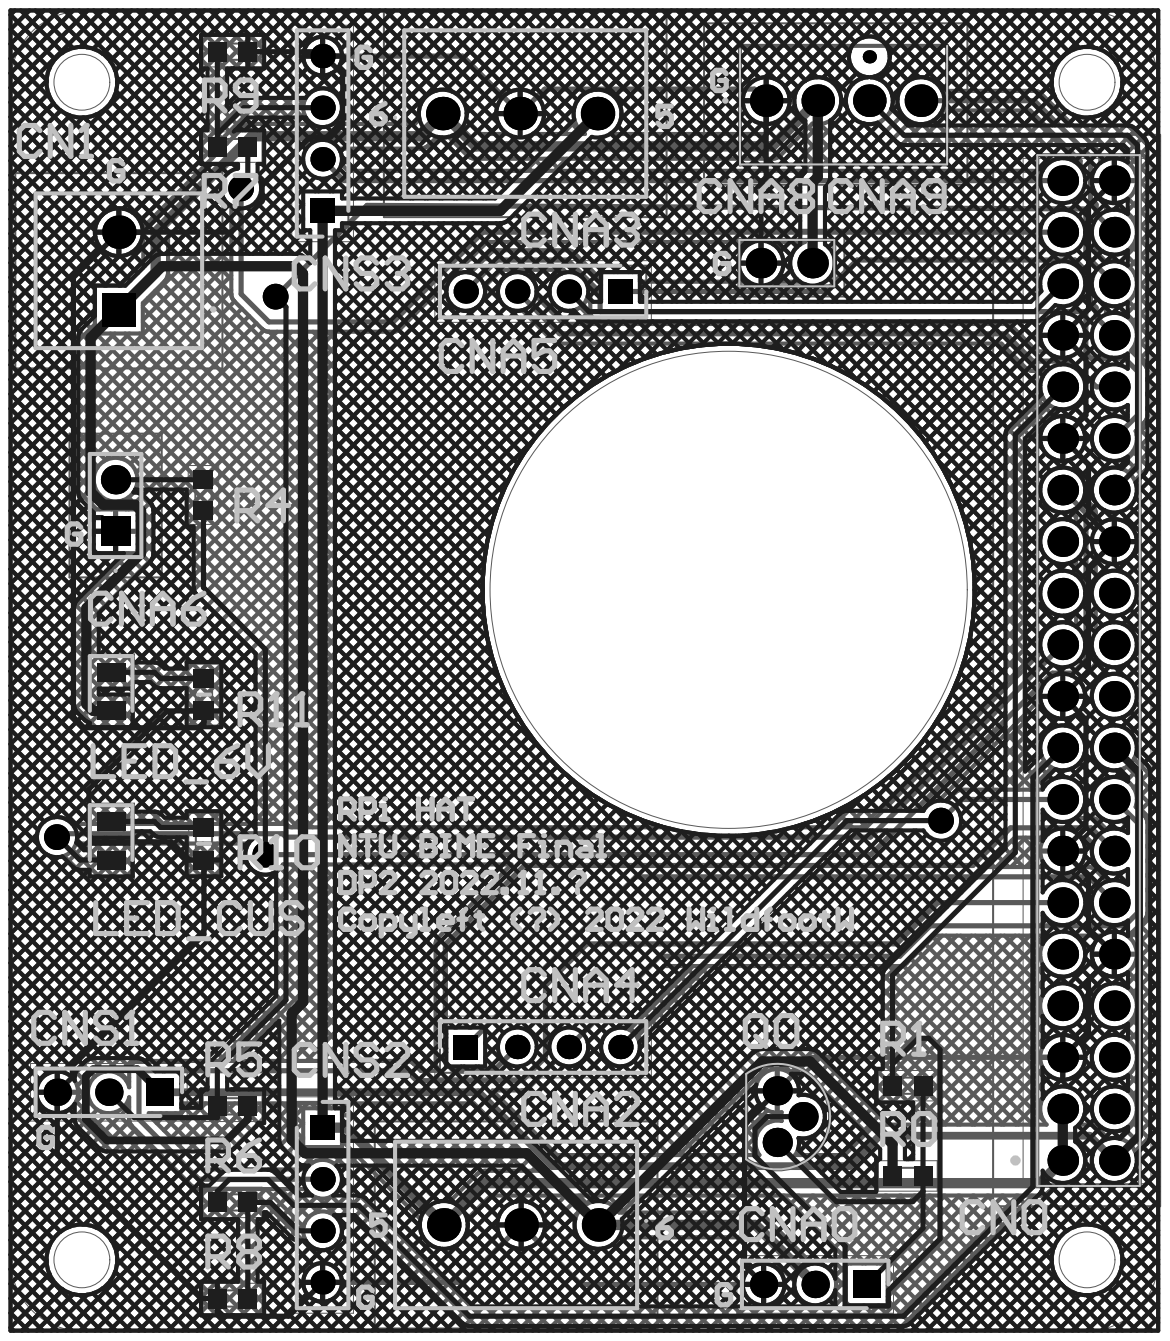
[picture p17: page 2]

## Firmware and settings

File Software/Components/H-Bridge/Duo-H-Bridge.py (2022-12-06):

import RPi.GPIO as GPIO
import time

#GPIO Mode (BOARD / BCM)
GPIO.setmode(GPIO.BOARD)

#set GPIO Pins
PWM2 = 11
PWM4 = 13
PWM6 = 15
PWM8 = 16
PWM3 = 33
PWM5 = 36
PWM7 = 31
PWM9 = 29

#set GPIO direction (IN / OUT)
GPIO.setup(PWM2, GPIO.OUT)
GPIO.setup(PWM4, GPIO.OUT)
GPIO.setup(PWM6, GPIO.OUT)
GPIO.setup(PWM8, GPIO.OUT)
GPIO.setup(PWM3, GPIO.OUT)
GPIO.setup(PWM5, GPIO.OUT)
GPIO.setup(PWM7, GPIO.OUT)
GPIO.setup(PWM9, GPIO.OUT)

def forward(sec):
    print("Forward")
    GPIO.output(PWM2, False)
    GPIO.output(PWM4, True)
    GPIO.output(PWM6, False)
    GPIO.output(PWM8, True)
    GPIO.output(PWM3, False)
    GPIO.output(PWM5, True)
    GPIO.output(PWM7, False)
    GPIO.output(PWM9, True)

def backward(sec):
    print("backward")
    GPIO.output(PWM2, True)
    GPIO.output(PWM4, False)

if __name__ == '__main__':
    try:
        seconds = 1
        while True:
#            time.sleep(seconds)
            forward(seconds)
            time.sleep(seconds)
#            backward(seconds)

        # Reset by pressing CTRL + C
    except KeyboardInterrupt:
        print("Stopped by User")
        GPIO.cleanup()

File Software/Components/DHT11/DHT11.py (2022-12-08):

# SPDX-FileCopyrightText: 2017 Limor Fried for Adafruit Industries
#
# SPDX-License-Identifier: MIT
# python3 -m pip install adafruit-circuitpython-dht
# https://github.com/adafruit/Adafruit_CircuitPython_DHT
# https://docs.circuitpython.org/projects/dht/en/3.0.1/

import time

import adafruit_dht
import board

dht = adafruit_dht.DHT11(board.D19)

while True:
    try:
        temperature = dht.temperature
        humidity = dht.humidity
        # Print what we got to the REPL
        if temperature and humidity:
            print("Temp: {%r} *C \t Humidity: {%r}" % (temperature, humidity))
    except RuntimeError as e:
        # Reading doesn't always work! Just print error and we'll try again
        print("Reading from DHT failure: ", e.args)

    time.sleep(1)

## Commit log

2022-11-04 Block Diagram: add power supply
2022-11-12 Mechanical: add Holder
    [HC-SR04 Holder.SLDPRT, Webcam Holder.SLDPRT]
2022-11-13 Update Electrical
    [BIME Final PCB.PrjPcb, BoardShape.DXF, BoardShape.SLDPRT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]
2022-11-25 Update Mechanical
    [Car Body Dock0.SLDPRT, HC-SR04 Holder.SLDPRT, HC-SR04 Holder.STL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]
2022-11-25 PCB Sheet Update
    [BIME Final PCB.PrjPcb, PCB1.PcbDoc, Sheet1.SchDoc]
2022-11-26 Gerber Final PCB DP1
    [BIME Final PCB.PrjPcb, BoardShape.DXF, BoardShape.SLDPRT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]
2022-11-26 Electrical: Update PDF
    [BIME Final PCB.PrjPcb, PCB1.PcbDoc]
2022-11-29 Mechanical: Initial All Components
    [Battery Dock.DXF, Battery Dock.SLDPRT, HC-SR04 Holder.SLDPRT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]
2022-12-04 ROS_PKG: update wheel_control receiver
2022-12-04 wheel_control.py: wait for test
2022-12-04 wheel_control: fix stop and wheel number
    [wheel_control.py]
2022-12-06 Mechanical: Update Main Dock
    [Main Dock.DXF, Main Dock.SLDPRT]
2022-12-07 RPi: Enable LED, Buzzer
    [ball_holder_control.py, buzzer_control.py, cpu_temperature_read.py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]
2022-12-07 sensor update
2022-12-08 Components SR04: update pin
2022-12-08 Thermal Fan: Enable
2022-12-08 update thermal fan
2022-12-15 Mechanical: fix typo Dock with Deck
    [Battery Deck.DXF, Battery Deck.SLDPRT, Main Deck.DXF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]
